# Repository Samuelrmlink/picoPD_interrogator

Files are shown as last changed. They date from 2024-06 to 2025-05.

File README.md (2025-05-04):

# picoPD_interrogator [Hardware Repository]
## __WARNING:__ The current hardware design version may have issues! Please see the 'Known Issues' section below.

If you're looking for firmware: [rp2040_pd_bmc](https://github.com/Samuelrmlink/rp2040_pd_bmc)

## Known issues
-------------------
[RevC-RC2]
* The NXP NX3DV3899 switch used to select CC lines doesn't actually connect common to either NC or even NO when the chip is unpowered. This was a design oversight when selecting this component for this use case. 
* Production of this PCB version is __NOT__ recommended.

[RevB]
* Everything works as expected design-wise
* This version lacks any voltage regulator for powering the Pico from VBUS power
* External USB power or a connected Flipper Zero may be used for operation

[RevA]
* USB-C port PCB footprint was incorrect & would not align with the target USB-C port (SM-G950 port)
* Comparator pins were connected incorrectly on this version - see RevB for the appropriate correction
* Production of this PCB version is __NOT__ recommended.

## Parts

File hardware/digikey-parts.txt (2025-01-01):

IC SWITCH SPDT X 1 15OHM SC70-6
1P1G3157QDCKRQ1
https://www.ti.com/general/docs/suppproductinfo.tsp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

Manufacturer PN

USB passthrough:
    USB TYPE C RECEPTACLE - ULTRA LO
    DX07BN24JA2R1300
    https://www.digikey.com/en/products/detail/jae-electronics/dx07bn24ja2r1300/10233365

    Dual double-pole double-throw analog switch
    IC SWITCH DPDT X 2 3.3OHM 16XQFN
    NX3DV3899GU,115
    https://www.nxp.com/docs/en/data-sheet/NX3DV3899.pdf

    IC SWITCH SPDT X 1 15OHM SC70-6
    1P1G3157QDCKRQ1
    https://www.ti.com/general/docs/suppproductinfo.tsp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

Voltage regulator:
    IC REG BUCK ADJ 600MA SOT23
    LV2862YDDCR & LV2862XLVDDCR
    https://www.digikey.com/en/products/detail/texas-instruments/LV2862YDDCR/15857122

    FIXED IND 22UH 220MA 1.25OHM SMD
    MLZ2012P220WT000
    https://www.digikey.com/en/products/detail/tdk-corporation/MLZ2012P220WT000/4327893

    DIODE SCHOTTKY 60V 1A SOD123FL
    DSS16U
    https://www.digikey.com/en/products/detail/smc-diode-solutions/DSS16U/8341861

    CAP CER 0.1UF 16V X5R 0201
    0201X104K160CT

    CAP CER 4.7UF 10V X5R 0603
    CL10A475KP8NNNC

    RES SMD 33K OHM 1% 1/20W 0201
    ERJ-1GNF3302C

    RES SMD 10K OHM 1% 1/20W 0201
    ERJ-1GNF1002C

    RES SMD 100K OHM 1% 1/20W 0201
    ERJ-1GNF1003C

Raspberry Pi RP2:
    CRYSTAL 12.0000MHZ 8PF SMD
    ABM10-166-12.000MHZ-T3

    RES SMD 1K OHM 1% 1/20W 0201
    ERJ-1GNF1001C

    CAP CER 15PF 25V C0G/NP0 0201
    GRM0335C1E150JA01D

    CAP CER 4.7UF 10V X5R 0603
    CL10A475KP8NNNC

    CAP CER 0.1UF 16V X5R 0201
    0201X104K160CT

    CONN HEADER SMD R/A 3POS 1MM
    SM03B-SRSS-TB

    CONN HEADER SMD R/A 4POS 1MM
    SM04B-SRSS-TB

    CONN HEADER SMD R/A 6POS 1MM
    SM06B-SRSS-TB

    SWITCH TACTILE SPST-NO 0.05A 12V
    PTS815SJG250SMTR LFS

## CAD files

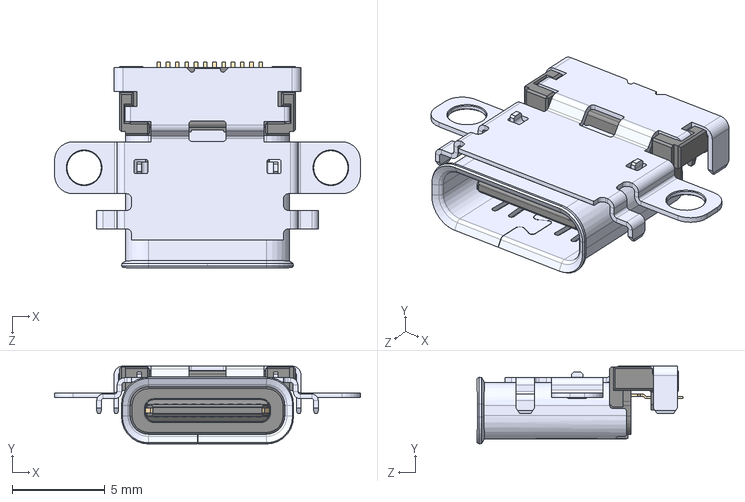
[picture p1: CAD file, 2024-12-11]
hardware/picoPD_interrogator/DX07BN24JA2R1300.step
16.5 x 4.20 x 11.1 mm

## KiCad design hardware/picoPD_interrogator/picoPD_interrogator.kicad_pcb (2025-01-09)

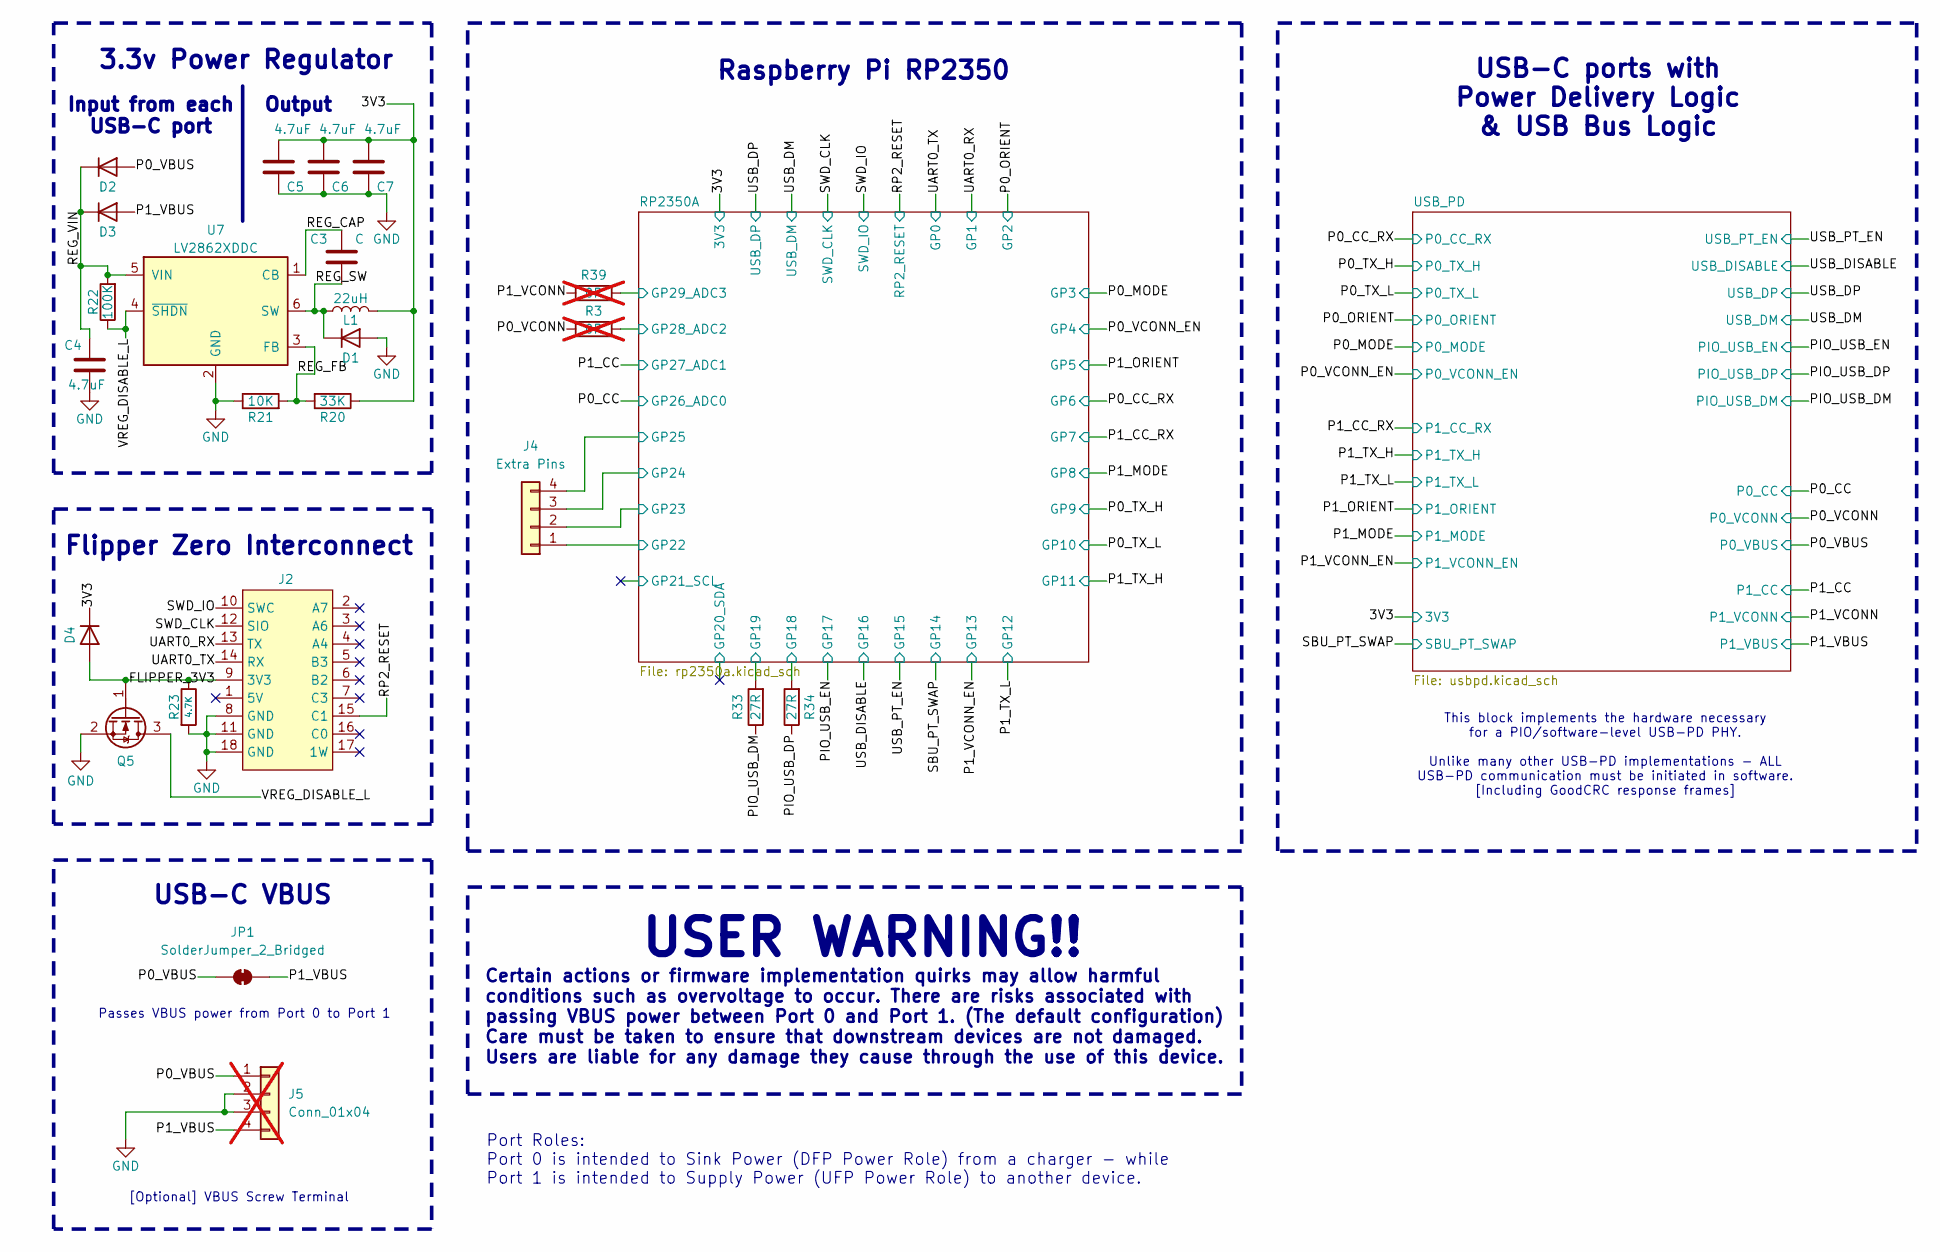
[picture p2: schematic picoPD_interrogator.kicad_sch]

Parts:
C3: C; C_0201_0603Metric; Manufacturer PN 0201X104K160CT
C4, C5, C6, C7: 4.7uF; C_0603_1608Metric; Manufacturer PN CL10A475KP8NNNC
D1, D2, D3, D4: D; D_SOD-123F; Manufacturer PN DSS16U
J2: SMD_FlipperZero_Expansion
J4: Extra Pins; PinHeader_1x04_P1.00mm_Vertical
J5: Conn_01x04; TerminalBlock_MaiXu_MX126-5.0-04P_1x04_P5.00mm; not fitted
JP1: SolderJumper_2_Bridged; SolderJumper-2_P1.3mm_Bridged_RoundedPad1.0x1.5mm
L1: 22uH; L_0805_2012Metric; Manufacturer PN MLZ2012P220WT000
Q5: rohm-RE1C002UN; SOT-416
R3, R39: 0R; R_0201_0603Metric; not fitted
R20: 33K; R_0201_0603Metric; Manufacturer PN ERJ-1GNF3302C
R21: 10K; R_0201_0603Metric; Manufacturer PN ERJ-1GNF1002C
R22: 100K; R_0201_0603Metric; Manufacturer PN ERJ-1GNF1003C
R23: 4.7K; R_0201_0603Metric; Manufacturer PN ERJ-1GNF4701C
R33, R34: 27R; R_0201_0603Metric
U7: LV2862XDDC; SOT-23-6

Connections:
/3V3: C5.1, C6.1, C7.1, D4.1 (K), L1.2, R20.1; also elsewhere on the board
/FLIPPER_3V3: D4.2 (A), J2.9 (3V3), Q5.1 (G), R23.1
/P0_VBUS: D2.2 (A), J5.1, JP1.1 (A); also elsewhere on the board
/P0_VCONN: R3.1; also elsewhere on the board
/P1_VBUS: D3.2 (A), J5.4, JP1.2 (B); also elsewhere on the board
/P1_VCONN: R39.1; also elsewhere on the board
/PIO_USB_DM: R33.1; also elsewhere on the board
/PIO_USB_DP: R34.1; also elsewhere on the board
/REG_CAP: C3.1, U7.1 (CB)
/REG_FB: R20.2, R21.2, U7.3 (FB)
/REG_SW: C3.2, D1.1 (K), L1.1, U7.6 (SW)
/REG_VIN: C4.2, D2.1 (K), D3.1 (K), R22.2, U7.5 (VIN)
/RP2_RESET: J2.15 (C1); also elsewhere on the board
/RP2350A/GP18: R34.2; also elsewhere on the board
/RP2350A/GP19: R33.2; also elsewhere on the board
/RP2350A/GP22: J4.1; also elsewhere on the board
/RP2350A/GP23: J4.2; also elsewhere on the board
/RP2350A/GP24: J4.3; also elsewhere on the board
/RP2350A/GP25: J4.4; also elsewhere on the board
/RP2350A/GP28_ADC2: R3.2; also elsewhere on the board
/RP2350A/GP29_ADC3: R39.2; also elsewhere on the board
/SWD_CLK: J2.12 (SIO); also elsewhere on the board
/SWD_IO: J2.10 (SWC); also elsewhere on the board
/UART0_RX: J2.13 (TX); also elsewhere on the board
/UART0_TX: J2.14 (RX); also elsewhere on the board
/VREG_DISABLE_L: Q5.3 (D), R22.1, U7.4 (~SHDN)
GND: C4.1, C5.2, C6.2, C7.2, D1.2 (A), J2.8 (GND), J2.11 (GND), J2.18 (GND), J5.2, J5.3, Q5.2 (S), R21.1, R23.2, U7.2 (GND); also elsewhere on the board

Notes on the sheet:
[Optional] VBUS Screw Terminal
Certain actions or firmware implementation quirks may allow harmful conditions such as overvoltage to occur. There are risks associated with passing VBUS power between Port 0 and Port 1. (The default configuration) Care must be taken to ensure that downstream devices are not damaged. Users are liab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
Output
Raspberry Pi RP2350
Passes VBUS power from Port 0 to Port 1
Input from each USB-C port
USB-C VBUS
Flipper Zero Interconnect
Port Roles: Port 0 is intended to Sink Power (DFP Power Role) from a charger - while Port 1 is intended to Supply Power (UFP Power Role) to another device.
USB-C ports with Power Delivery Logic & USB Bus Logic
This block implements the hardware necessary for a PIO/software-level USB-PD PHY. Unlike many other USB-PD implementations - ALL USB-PD communication must be initiated in software. [Including GoodCRC response frames]
USER WARNING!!
3.3v Power Regulator

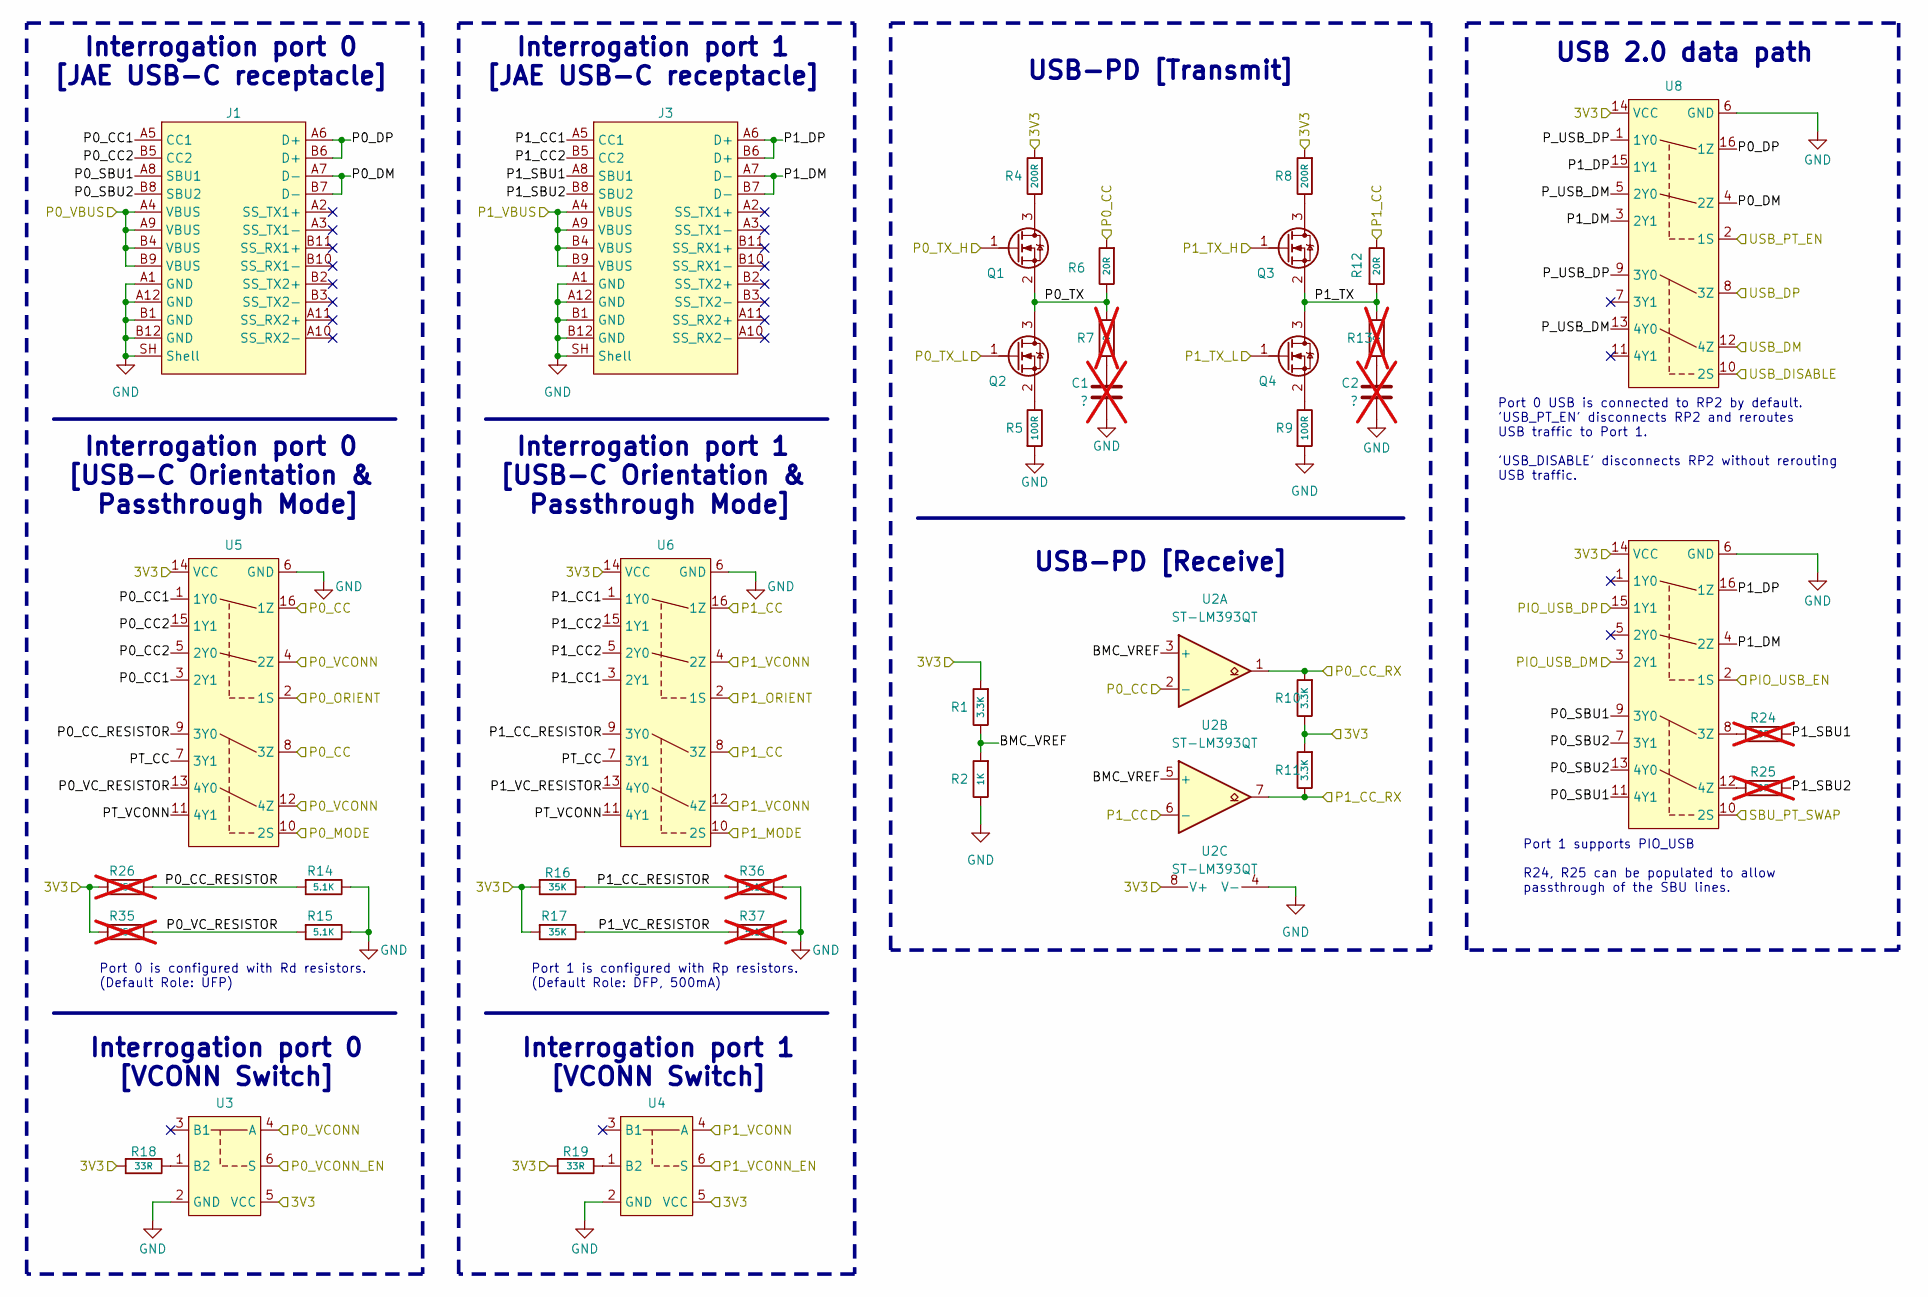
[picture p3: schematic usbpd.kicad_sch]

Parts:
C1, C2: ?; C_0201_0603Metric; not fitted
J1, J3: JAE_DX07BN24JA2R1300
Q1, Q2, Q3, Q4: rohm-RE1C002UN; SOT-416
R1, R10, R11: 3.3K; R_0201_0603Metric; Manufacturer PN ERJ-1GNF3301C
R2: 1K; R_0201_0603Metric; Manufacturer PN ERJ-1GNF1001C
R4, R8: 200R; R_0201_0603Metric; Manufacturer PN ERJ-1GNF2000C
R5, R9: 100R; R_0201_0603Metric; Manufacturer PN ERJ-1GNF1000C
R6, R12: 20R; R_0201_0603Metric; Manufacturer PN ERJ-1GNF20R0C
R7, R13: ?; R_0201_0603Metric; not fitted
R14, R15: 5.1K; R_0201_0603Metric; Manufacturer PN ERJ-1GNF5101C
R16, R17: 35K; R_0201_0603Metric; Manufacturer PN ERJ-1GNF4701C
R18, R19: 33R; R_0201_0603Metric; Manufacturer PN ERJ-1GNF33R0C
R24, R25: 0R; R_0201_0603Metric; Manufacturer PN ERJ-1GNF20R0C; not fitted
R26, R35: 35K; R_0201_0603Metric; Manufacturer PN ERJ-1GNF5101C; not fitted
R36, R37: 5.1K; R_0201_0603Metric; Manufacturer PN ERJ-1GNF5101C; not fitted
U2: ST-LM393QT; DFN-8_2x2mm_P0.5mm_ST; Manufacturer PN LM393QT
U3, U4: TI_sn741vc1g3157-q1; Manufacturer PN 1P1G3157QDCKRQ1
U5, U6, U8, U9: NXP_NX3DV3899GU; Manufacturer PN NX3DV3899GU,115

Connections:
/3V3: R1.2, R4.2, R8.2, R10.1, R11.2, R16.2, R17.2, R18.2, R19.2, R26.2, R35.2, U2.8 (V+), U3.5 (VCC), U4.5 (VCC), U5.14 (VCC), U6.14 (VCC), U8.14 (VCC), U9.14 (VCC); also elsewhere on the board
/P0_CC: R6.2, U2.2 (-), U5.8 (3Z), U5.16 (1Z); also elsewhere on the board
/P0_CC_RX: R10.2, U2.1; also elsewhere on the board
/P0_MODE: U5.10 (2S); also elsewhere on the board
/P0_ORIENT: U5.2 (1S); also elsewhere on the board
/P0_TX_H: Q1.1 (G); also elsewhere on the board
/P0_TX_L: Q2.1 (G); also elsewhere on the board
/P0_VBUS: J1.A4 (VBUS), J1.A9 (VBUS), J1.B4 (VBUS), J1.B9 (VBUS); also elsewhere on the board
/P0_VCONN: U3.4 (A), U5.4 (2Z), U5.12 (4Z); also elsewhere on the board
/P0_VCONN_EN: U3.6 (S); also elsewhere on the board
/P1_CC: R12.1, U2.6 (-), U6.8 (3Z), U6.16 (1Z); also elsewhere on the board
/P1_CC_RX: R11.1, U2.7; also elsewhere on the board
/P1_MODE: U6.10 (2S); also elsewhere on the board
/P1_ORIENT: U6.2 (1S); also elsewhere on the board
/P1_TX_H: Q3.1 (G); also elsewhere on the board
/P1_TX_L: Q4.1 (G); also elsewhere on the board
/P1_VBUS: J3.A4 (VBUS), J3.A9 (VBUS), J3.B4 (VBUS), J3.B9 (VBUS); also elsewhere on the board
/P1_VCONN: U4.4 (A), U6.4 (2Z), U6.12 (4Z); also elsewhere on the board
/P1_VCONN_EN: U4.6 (S); also elsewhere on the board
/PIO_USB_DM: U9.3 (2Y1); also elsewhere on the board
/PIO_USB_DP: U9.15 (1Y1); also elsewhere on the board
/PIO_USB_EN: U9.2 (1S); also elsewhere on the board
/SBU_PT_SWAP: U9.10 (2S); also elsewhere on the board
/USB_DISABLE: U8.10 (2S); also elsewhere on the board
/USB_DM: U8.12 (4Z); also elsewhere on the board
/USB_DP: U8.8 (3Z); also elsewhere on the board
/USB_PD/BMC_VREF: R1.1, R2.2, U2.3 (+), U2.5 (+)
/USB_PD/P0_CC1: J1.A5 (CC1), U5.1 (1Y0), U5.3 (2Y1)
/USB_PD/P0_CC2: J1.B5 (CC2), U5.5 (2Y0), U5.15 (1Y1)
/USB_PD/P0_CC_RESISTOR: R14.2, R26.1, U5.9 (3Y0)
/USB_PD/P0_DM: J1.A7 (D-), J1.B7 (D-), U8.4 (2Z)
/USB_PD/P0_DP: J1.A6 (D+), J1.B6 (D+), U8.16 (1Z)
/USB_PD/P0_SBU1: J1.A8 (SBU1), U9.9 (3Y0), U9.11 (4Y1)
/USB_PD/P0_SBU2: J1.B8 (SBU2), U9.7 (3Y1), U9.13 (4Y0)
/USB_PD/P0_TX: Q1.2 (S), Q2.3 (D), R6.1, R7.2
/USB_PD/P0_VC_RESISTOR: R15.2, R35.1, U5.13 (4Y0)
/USB_PD/P1_CC1: J3.A5 (CC1), U6.1 (1Y0), U6.3 (2Y1)
/USB_PD/P1_CC2: J3.B5 (CC2), U6.5 (2Y0), U6.15 (1Y1)
/USB_PD/P1_CC_RESISTOR: R16.1, R36.2, U6.9 (3Y0)
/USB_PD/P1_DM: J3.A7 (D-), J3.B7 (D-), U8.3 (2Y1), U9.4 (2Z)
/USB_PD/P1_DP: J3.A6 (D+), J3.B6 (D+), U8.15 (1Y1), U9.16 (1Z)
/USB_PD/P1_SBU1: J3.A8 (SBU1), R24.2
/USB_PD/P1_SBU2: J3.B8 (SBU2), R25.2
/USB_PD/P1_TX: Q3.2 (S), Q4.3 (D), R12.2, R13.2
/USB_PD/P1_VC_RESISTOR: R17.1, R37.2, U6.13 (4Y0)
/USB_PD/PT_CC: U5.7 (3Y1), U6.7 (3Y1)
/USB_PD/PT_VCONN: U5.11 (4Y1), U6.11 (4Y1)
/USB_PD/P_USB_DM: U8.5 (2Y0), U8.13 (4Y0)
/USB_PD/P_USB_DP: U8.1 (1Y0), U8.9 (3Y0)
/USB_PT_EN: U8.2 (1S); also elsewhere on the board
GND: C1.2, C2.2, J1.A1 (GND), J1.A12 (GND), J1.B1 (GND), J1.B12 (GND), J1.SH (Shell), J3.A1 (GND), J3.A12 (GND), J3.B1 (GND), J3.B12 (GND), J3.SH (Shell), R2.1, R5.2, R9.2, R14.1, R15.1, R36.1, R37.1, U2.4 (V-), U3.2 (GND), U4.2 (GND), U5.6 (GND), U6.6 (GND), U8.6 (GND), U9.6 (GND); also elsewhere on the board
unnamed: C1.1, R7.1
unnamed: C2.1, R13.1
unnamed: Q1.3 (D), R4.1
unnamed: Q2.2 (S), R5.1
unnamed: Q3.3 (D), R8.1
unnamed: Q4.2 (S), R9.1
unnamed: R18.1, U3.1 (B2)
unnamed: R19.1, U4.1 (B2)
unnamed: R24.1, U9.8 (3Z)
unnamed: R25.1, U9.12 (4Z)

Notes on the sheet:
Port 1 is configured with Rp resistors. (Default Role: DFP, 500mA)
USB 2.0 data path
Port 1 supports PIO_USB R24, R25 can be populated to allow passthrough of the SBU lines.
Port 0 is configured with Rd resistors. (Default Role: UFP)
USB-PD [Receive]
Interrogation port 0 [USB-C Orientation & Passthrough Mode]
Interrogation port 1 [VCONN Switch]
Interrogation port 0 [VCONN Switch]
USB-PD [Transmit]
Interrogation port 0 [JAE USB-C receptacle]
Port 0 USB is connected to RP2 by default. 'USB_PT_EN' disconnects RP2 and reroutes USB traffic to Port 1. 'USB_DISABLE' disconnects RP2 without rerouting USB traffic.
Interrogation port 1 [JAE USB-C receptacle]
Interrogation port 1 [USB-C Orientation & Passthrough Mode]

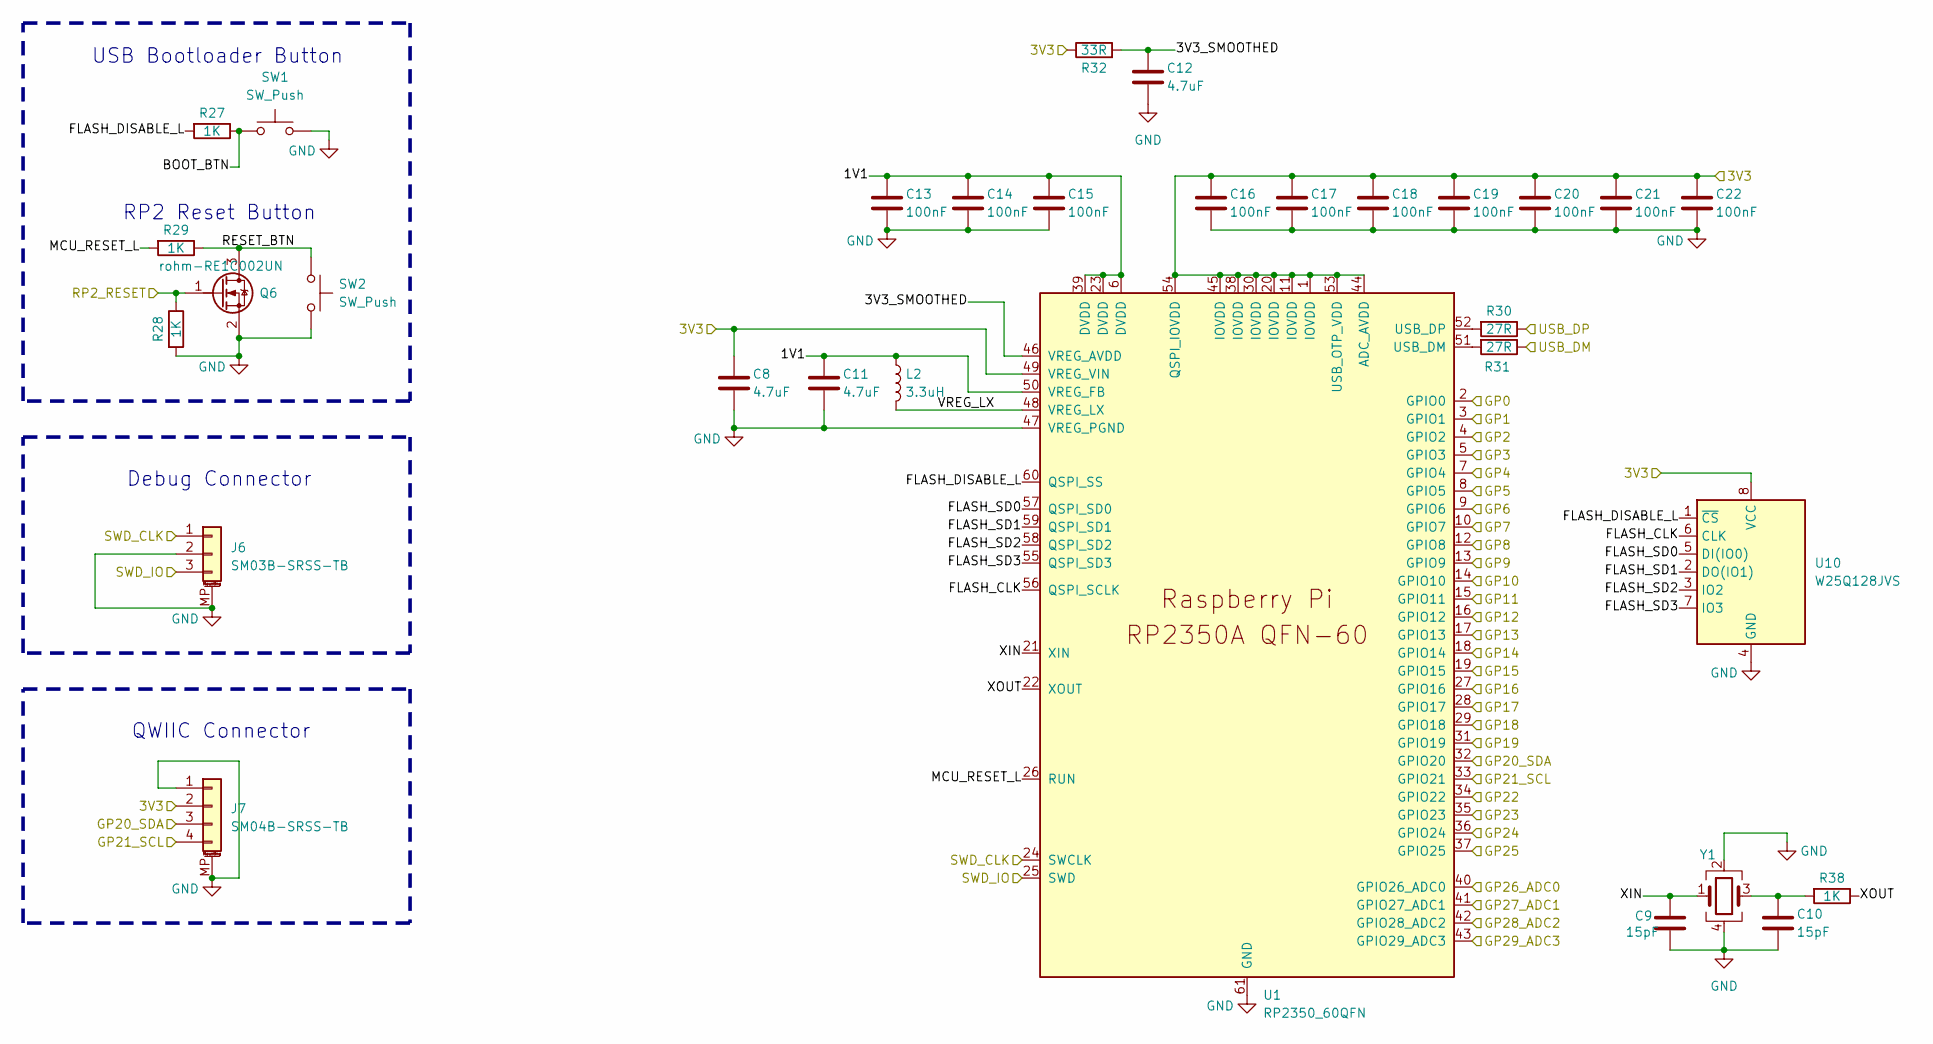
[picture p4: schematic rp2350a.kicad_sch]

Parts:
C8, C11, C12: 4.7uF; C_0603_1608Metric
C9, C10: 15pF; C_0201_0603Metric
C13, C14, C15, C16, C17, C18, C19, C20, C21, C22: 100nF; C_0201_0603Metric
J6: SM03B-SRSS-TB; JST_SH_SM03B-SRSS-TB_1x03-1MP_P1.00mm_Horizontal
J7: SM04B-SRSS-TB; JST_SH_SM04B-SRSS-TB_1x04-1MP_P1.00mm_Horizontal
L2: 3.3uH; L_pol_2016
Q6: rohm-RE1C002UN; SOT-416
R27, R28, R29, R38: 1K; R_0201_0603Metric
R30, R31: 27R; R_0201_0603Metric
R32: 33R; R_0201_0603Metric
SW1, SW2: SW_Push; CK_PTS815
U1: RP2350_60QFN; RP2350-QFN-60-1EP_7x7_P0.4mm_EP3.4x3.4mm_ThermalVias
U10: W25Q128JVS; SOIC-8_5.23x5.23mm_P1.27mm
Y1: Crystal_GND24; Crystal_SMD_Abracon_ABM10-4Pin_2.5x2.0mm

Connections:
/3V3: C8.1, C16.1, C17.1, C18.1, C19.1, C20.1, C21.1, C22.1, J7.2, R32.1, U1.1 (IOVDD), U1.11 (IOVDD), U1.20 (IOVDD), U1.30 (IOVDD), U1.38 (IOVDD), U1.44 (ADC_AVDD), U1.45 (IOVDD), U1.49 (VREG_VIN), U1.53 (USB_OTP_VDD), U1.54 (QSPI_IOVDD), U10.8 (VCC); also elsewhere on the board
/P0_CC: U1.40 (GPIO26_ADC0); also elsewhere on the board
/P0_CC_RX: U1.9 (GPIO6); also elsewhere on the board
/P0_MODE: U1.5 (GPIO3); also elsewhere on the board
/P0_ORIENT: U1.4 (GPIO2); also elsewhere on the board
/P0_TX_H: U1.13 (GPIO9); also elsewhere on the board
/P0_TX_L: U1.14 (GPIO10); also elsewhere on the board
/P0_VCONN_EN: U1.7 (GPIO4); also elsewhere on the board
/P1_CC: U1.41 (GPIO27_ADC1); also elsewhere on the board
/P1_CC_RX: U1.10 (GPIO7); also elsewhere on the board
/P1_MODE: U1.12 (GPIO8); also elsewhere on the board
/P1_ORIENT: U1.8 (GPIO5); also elsewhere on the board
/P1_TX_H: U1.15 (GPIO11); also elsewhere on the board
/P1_TX_L: U1.16 (GPIO12); also elsewhere on the board
/P1_VCONN_EN: U1.17 (GPIO13); also elsewhere on the board
/PIO_USB_EN: U1.28 (GPIO17); also elsewhere on the board
/RP2_RESET: Q6.1 (G), R28.1; also elsewhere on the board
/RP2350A/1V1: C11.1, C13.1, C14.1, C15.1, L2.1, U1.6 (DVDD), U1.23 (DVDD), U1.39 (DVDD), U1.50 (VREG_FB)
/RP2350A/3V3_SMOOTHED: C12.1, R32.2, U1.46 (VREG_AVDD)
/RP2350A/BOOT_BTN: R27.1, SW1.1
/RP2350A/FLASH_CLK: U1.56 (QSPI_SCLK), U10.6 (CLK)
/RP2350A/FLASH_DISABLE_L: R27.2, U1.60 (QSPI_SS), U10.1 (~CS)
/RP2350A/FLASH_SD0: U1.57 (QSPI_SD0), U10.5 (DI(IO0))
/RP2350A/FLASH_SD1: U1.59 (QSPI_SD1), U10.2 (DO(IO1))
/RP2350A/FLASH_SD2: U1.58 (QSPI_SD2), U10.3 (IO2)
/RP2350A/FLASH_SD3: U1.55 (QSPI_SD3), U10.7 (IO3)
/RP2350A/GP18: U1.29 (GPIO18); also elsewhere on the board
/RP2350A/GP19: U1.31 (GPIO19); also elsewhere on the board
/RP2350A/GP20_SDA: J7.3, U1.32 (GPIO20)
/RP2350A/GP21_SCL: J7.4, U1.33 (GPIO21)
/RP2350A/GP22: U1.34 (GPIO22); also elsewhere on the board
/RP2350A/GP23: U1.35 (GPIO23); also elsewhere on the board
/RP2350A/GP24: U1.36 (GPIO24); also elsewhere on the board
/RP2350A/GP25: U1.37 (GPIO25); also elsewhere on the board
/RP2350A/GP28_ADC2: U1.42 (GPIO28_ADC2); also elsewhere on the board
/RP2350A/GP29_ADC3: U1.43 (GPIO29_ADC3); also elsewhere on the board
/RP2350A/MCU_RESET_L: R29.2, U1.26 (RUN)
/RP2350A/RESET_BTN: Q6.3 (D), R29.1, SW2.1
/RP2350A/VREG_LX: L2.2, U1.48 (VREG_LX)
/RP2350A/XIN: C9.1, U1.21 (XIN), Y1.1
/RP2350A/XOUT: R38.1, U1.22 (XOUT)
/SBU_PT_SWAP: U1.18 (GPIO14); also elsewhere on the board
/SWD_CLK: J6.1, U1.24 (SWCLK); also elsewhere on the board
/SWD_IO: J6.3, U1.25 (SWD); also elsewhere on the board
/UART0_RX: U1.3 (GPIO1); also elsewhere on the board
/UART0_TX: U1.2 (GPIO0); also elsewhere on the board
/USB_DISABLE: U1.27 (GPIO16); also elsewhere on the board
/USB_DM: R31.1; also elsewhere on the board
/USB_DP: R30.1; also elsewhere on the board
/USB_PT_EN: U1.19 (GPIO15); also elsewhere on the board
GND: C8.2, C9.2, C10.2, C11.2, C12.2, C13.2, C14.2, C15.2, C16.2, C17.2, C18.2, C19.2, C20.2, C21.2, C22.2, J6.2, J6.MP (MountPin), J7.1, J7.MP (MountPin), Q6.2 (S), R28.2, SW1.2, SW2.2, U1.47 (VREG_PGND), U1.61 (GND), U10.4 (GND), Y1.2, Y1.4; also elsewhere on the board
unnamed: C10.1, R38.2, Y1.3
unnamed: R31.2, U1.51 (USB_DM)
unnamed: R30.2, U1.52 (USB_DP)

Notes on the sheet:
QWIIC Connector
RP2 Reset Button
USB Bootloader Button
Debug Connector

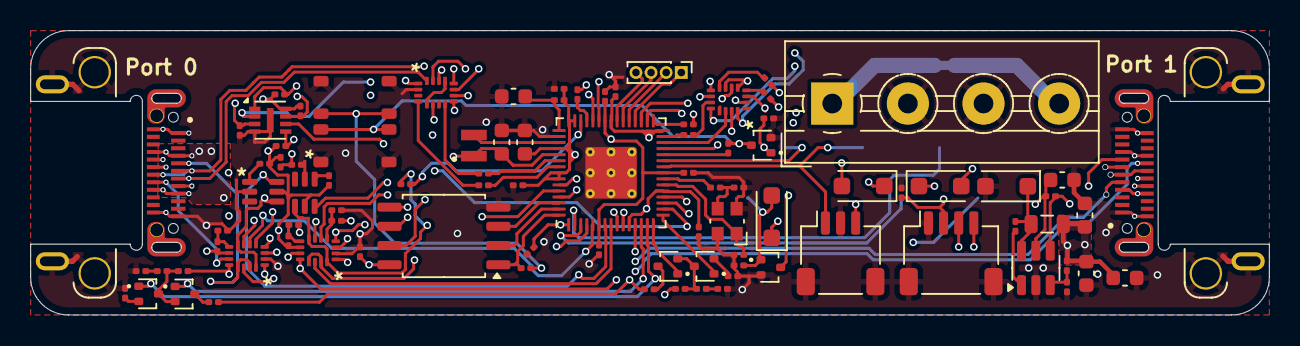
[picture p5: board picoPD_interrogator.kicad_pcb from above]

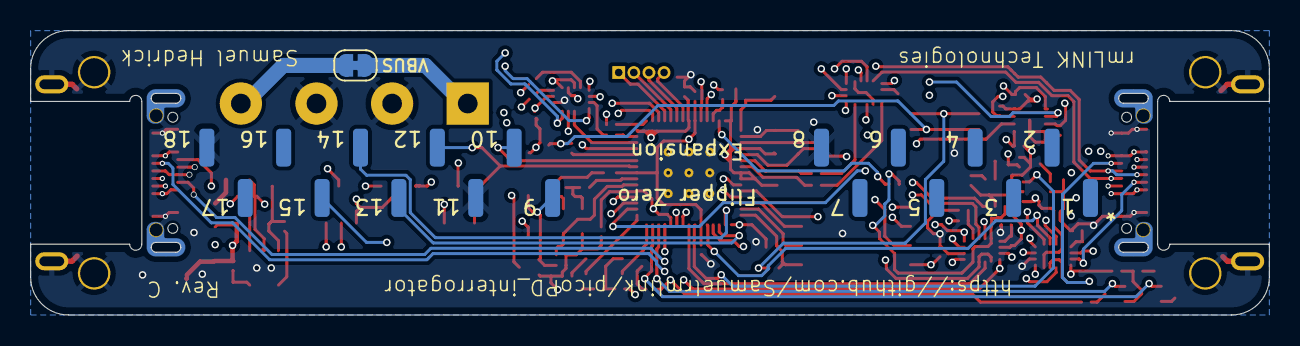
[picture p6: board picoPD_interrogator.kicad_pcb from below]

Board: 4 copper layers, 81.9 x 18.8 mm, 94 parts (2 on the bottom side), 99 nets.

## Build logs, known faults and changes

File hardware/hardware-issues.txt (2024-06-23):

Rev. A:
	No CC pull-down resistors (should be pulled down via n-channel fet)
	USB-C connector footprint does not match the part (GS8 USB-C port)
	Incorrect input pin assignment (swap + and - inputs)

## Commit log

2024-05-04 Initial commit. Added some component footprints and symbols.
    [picoPD_interrogator.kicad_pcb, picoPD_interrogator.kicad_sch]
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2024-05-12 Added mosfets to the schematic diagram.
    [picoPD_interrogator.kicad_sch]
2024-05-14 Added FlipperZero SMD Expansion connector footprint.
2024-05-18 Getting started with PCB component placement.
    [picoPD_interrogator.kicad_pcb]
2024-05-18 Added FlipperDevices-FlipperZeroExpansion connector symbol.
    [picoPD_interrogator.kicad_sch]
2024-05-18 Added some resistors and lines to schematic.
    [picoPD_interrogator.kicad_sch]
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2024-05-19 Added testpoints to schematic.
    [picoPD_interrogator.kicad_sch]
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2024-05-19 Defined footprints for each relevant symbol on the schematic.
    [picoPD_interrogator.kicad_sch]
2024-05-19 Fixed footprint pin numbers.
    [picoPD_interrogator.kicad_sch]
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2024-05-19 Fixed position of header pins connector.
    [picoPD_interrogator.kicad_pcb]
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2024-05-20 Added 3.3v fill on the F.Cu layer.
    [picoPD_interrogator.kicad_pcb]
2024-05-20 Placing components... Also added the B.Cu GND layer fill.
    [picoPD_interrogator.kicad_pcb]
2024-05-25 Added additional pads to the underside of the RaspberryPiFoundation Pico Footprint.
    [picoPD_interrogator.kicad_pcb]
2024-05-25 Working on PCB route.
    [picoPD_interrogator.kicad_pcb, picoPD_interrogator.kicad_sch]
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2024-05-26 Routed traces - also removed one of the unused pads for the flipper zero header connection.
    [picoPD_interrogator.kicad_pcb]
2024-05-26 First production candidate for Rev. A
    [picoPD_interrogator.kicad_pcb]
2024-06-23 Schematic - swapped comparator + and - inputs.
    [picoPD_interrogator.kicad_sch]
2024-06-24 Schematic - Added Rd pulldown resistors.
    [picoPD_interrogator.kicad_sch]
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2024-06-26 PCB: Rerouted pads for USB-C GS8 connector. [Footprint was changed in a previous commit.]
    [picoPD_interrogator.kicad_pcb]
2024-06-26 PCB: Fixed comparator tracks. Added 5.1K CC pull-downs to the PCB.
    [picoPD_interrogator.kicad_pcb]
2024-06-26 PCB: Modified board revision silk-screen. Rev. A ---> Rev. B
    [picoPD_interrogator.kicad_pcb]
2024-12-02 Seperated out RPI Pico MCU module on schematic.
    [picoPD_interrogator.kicad_sch]
2024-12-02 Cleaned up schematic layout.
    [picoPD_interrogator.kicad_sch]
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2024-12-08 Added DPDT switch for connector orientation & passthrough mode.
    [picoPD_interrogator.kicad_sch]
2024-12-08 Added netlist-notes.txt - which will be used to keep track of which netlists are being removed/replaced during schematic capture.
2024-12-09 Schematic: Added second interrogator port.
    [picoPD_interrogator.kicad_sch]
2024-12-11 Schematic: Added VCONN switches.
    [picoPD_interrogator.kicad_sch]
2024-12-11 Added JAE DX07BN24JA2R1300 USB-C receptacle footprint and step files.
    [DX07BN24JA2R1300.step]
2024-12-11 Schematic: Working on TI voltage regulator.
    [picoPD_interrogator.kicad_sch]
2024-12-12 Schematic: Added 'Manufacturer PN' field as well as Descriptions to many components.
    [picoPD_interrogator.kicad_sch]
2024-12-12 Schematic: Added 3.3v buck converter circuit.
    [picoPD_interrogator.kicad_sch]
2024-12-12 Schematic: Shut down 3V3 reg while flipper is attached.
    [picoPD_interrogator.kicad_sch]
2024-12-14 Schematic: Moved USB-PD stuff to a seperate page for space purposes. Also created a page for the RP2 components.
    [picoPD_interrogator.kicad_sch, rp2350a.kicad_sch, usbpd.kicad_sch]
2024-12-14 Schematic: Changed hierarchical labels to regular labels. [USB-PD page]
    [usbpd.kicad_sch]
2024-12-14 Schematic: Imported USB-PD hierarchical labels to the main page.
    [picoPD_interrogator.kicad_sch]
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2024-12-20 Symbol: Corrected the footprint Library link.
2024-12-20 Added most of the RP2350A parts.
    [rp2350a.kicad_sch]
2024-12-21 Schematic: Changed Port 1 Rp value to 56K - indicating only 500ma of current can be drawn by a downstream device without a PD contract.
    [usbpd.kicad_sch]
2024-12-21 Schematic: Added QWIIC Connector. Changed 56K Rp resistor to 35K since we are pulling up 3.3v instead of 5v.
    [picoPD_interrogator.kicad_sch, rp2350a.kicad_sch, usbpd.kicad_sch]
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2024-12-21 Schematic: Added an 'Extra Pins' connector.
    [picoPD_interrogator.kicad_sch, rp2350a.kicad_sch]
2024-12-21 Schematic: Removed the Pico module since it has been implemented directed on the PCB.
    [picoPD_interrogator.kicad_sch]
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2024-12-31 Schematic: Added VBUS Terminal Block connector & Warning message.
    [picoPD_interrogator.kicad_sch, usbpd.kicad_sch]
2024-12-31 Schematic: Changed VBUS Terminal to DNP.
    [picoPD_interrogator.kicad_sch]
2024-12-31 Schematic: Marked some filtering passives as DNP. Annotated schematic.
    [rp2350a.kicad_sch, usbpd.kicad_sch]
2024-12-31 Footprint: Shrunk the FlipperZero_Expansion connector footprint.
2024-12-31 Footprint: Shrunk the FlipperZero_Expansion connector courtyard even further. (So that it would not complain about GND vias between the two Flipper connectors.)
2024-12-31 PCB: Started work on the new board layout.
    [picoPD_interrogator.kicad_pcb, picoPD_interrogator.kicad_sch]
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2025-01-01 PCB: Setup board outline.
    [picoPD_interrogator.kicad_pcb]
2025-01-01 PCB: Working on board layout.
    [picoPD_interrogator.kicad_pcb]
2025-01-01 PCB: Working on PCB layout.
    [picoPD_interrogator.kicad_pcb]
2025-01-01 PCB: Routed USB and SBU traces. (Intended only for Full/Low Speed testing - USB) (Intended only for UART debugging - SBU lines)
    [picoPD_interrogator.kicad_pcb, picoPD_interrogator.kicad_sch]
2025-01-02 PCB: Working on the main 3.3v regulator.
    [picoPD_interrogator.kicad_pcb, picoPD_interrogator.kicad_sch]
2025-01-02 Footprint: Modified the JAE USB-C connection courtyard and applied to the PCB.
    [picoPD_interrogator.kicad_pcb]
2025-01-02 Schematic/PCB: Changed the reset circuit & the reset circuit PCB layout.
    [picoPD_interrogator.kicad_pcb, rp2350a.kicad_sch]
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2025-01-02 PCB: Working on routing. Routed Port_1 control GPIOs.
    [picoPD_interrogator.kicad_pcb]
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2025-01-03 PCB: Routing traces.. CC/VCONN ADC lines are routed.
    [picoPD_interrogator.kicad_pcb, picoPD_interrogator.kicad_sch]
2025-01-07 PCB: Rerouted many lines to make room for more vias.
    [picoPD_interrogator.kicad_pcb]
2025-01-08 Routed almost everything. Just need to finish VBUS tracks and check for any obvious issues.
    [picoPD_interrogator.kicad_pcb, usbpd.kicad_sch]
2025-01-08 PCB: Resolve a bunch of clearance DRC errors.
    [picoPD_interrogator.kicad_pcb]
2025-01-08 Footprint/PCB: Modified JAE USB-C connector to have plated through-hole for the screw mount holes. Fixed missing SPI flash track.
    [picoPD_interrogator.kicad_pcb]
2025-01-08 PCB: Added silkscreen text and board revision. (Rev. C)
    [picoPD_interrogator.kicad_pcb]
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2025-01-09 Fixing spacing issues for PCBWay manufacturing.
    [picoPD_interrogator.kicad_pcb]
2025-01-09 PCB: Reworked for the second try with PCBWAY.
    [picoPD_interrogator.kicad_pcb]
